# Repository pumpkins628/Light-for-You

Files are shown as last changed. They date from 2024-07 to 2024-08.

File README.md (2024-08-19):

# LightVest🚦 Smart Turn Signal Vest
Welcome to the **LightVest** project! This wearable vest is designed to enhance cyclists' and motorcyclists' safety by providing clear, visible turn signals and hazard lights.
👇 ***Click the image below to watch the introduction video!*** 🎥

<p align="center">
  <a href="https://vm.tiktok.com/ZGe3J54N1/">
    Click to watch the video
  </a>
</p>

## ✨ Features

- **Bluetooth Connectivity**: Automatically connects the vest and remote controller.
- **Button Control**: Control the lights using a handlebar-mounted remote with left, right, and hazard buttons.
- **Automatic Detection**: The vest automatically detects handlebar turns and activates the corresponding signal.
- **Emergency Lights**: Activate hazard lights with a single button press for added safety.
- **Easy to Remove and Clean**: The LED strips are designed to be easily detachable for convenient cleaning.
- **Easy Battery Replacement**: The battery compartment is designed for quick and simple replacement.

## 🛠️ Installation

### Hardware Setup

1. #### Components

| Component | Quantity | Description |
|:---:|:---:|:---:|
| **Arduino Nano** | 2 | Microcontroller for control and communication |
| **Bluetooth Modules (HC-05)** | 2 | For wireless communication between the Arduinos |
| **Accelerometer (MPU6050)** | 1 | Detect handlebar angle |
| **LED Strips** | 1 | For displaying turn signals on the vest |
| **Push buttons** | 2 | Control left, right light |
| **Torch switches** | 1 | Control hazard lights |
| **Battery holder** | 2 | Hold and connect AA batteries |
| **AA batteries** | 6 | Power supply for the vest and remote |
| **Jumper wires** | Several  | For connecting components |
| **Resistors** | Various  | To limit current and protect components |
| **Capacitors** | Various  | For filtering and stabilizing voltage |

2. #### Assembly

 **Bluetooth Pairing**:
   - Use a serial debugging tool to pair the two Bluetooth modules. The relevant software can be found in the `Test` folder.
   
 **Wiring the Components**:
   - Connect all components according to the wiring diagrams provided. The diagrams for the two sections are shown below:
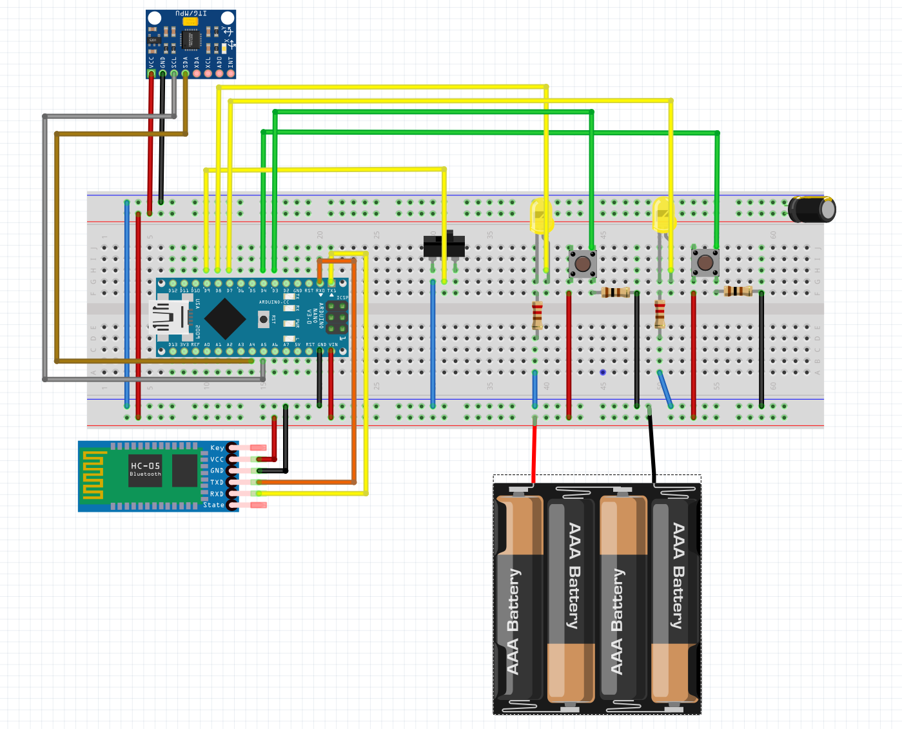
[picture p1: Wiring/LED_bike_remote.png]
Remote Wiring
     - **Remote Controller Wiring Diagram**: 
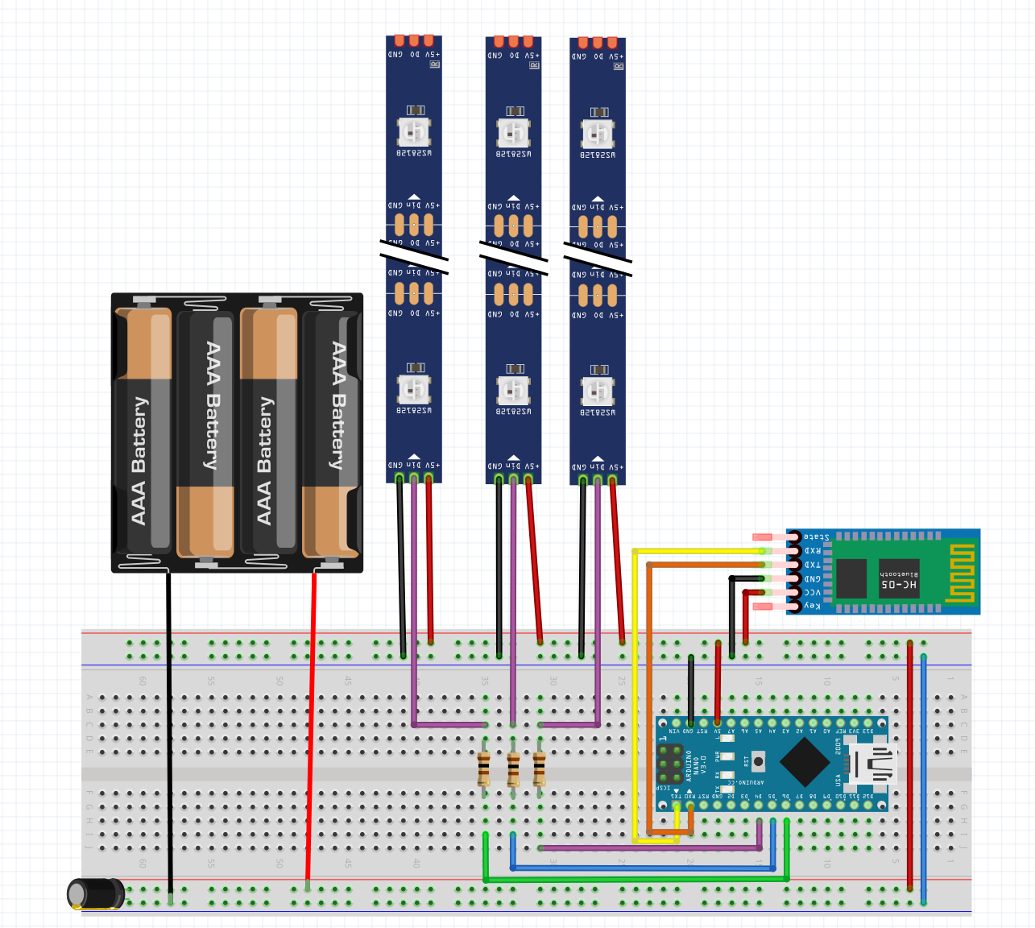
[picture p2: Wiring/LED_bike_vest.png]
Vest Wiring
     - **Vest Wiring Diagram**: 
     
 **PCB Design**:
- The PCB design files are located in the `PCB` folder. If you wish to have your own vest, feel free to download them.

3. #### Enclosure
   - The 3D printing files for the enclosure are located in the `3D_Print` folder. Below is a preview of the enclosure design:
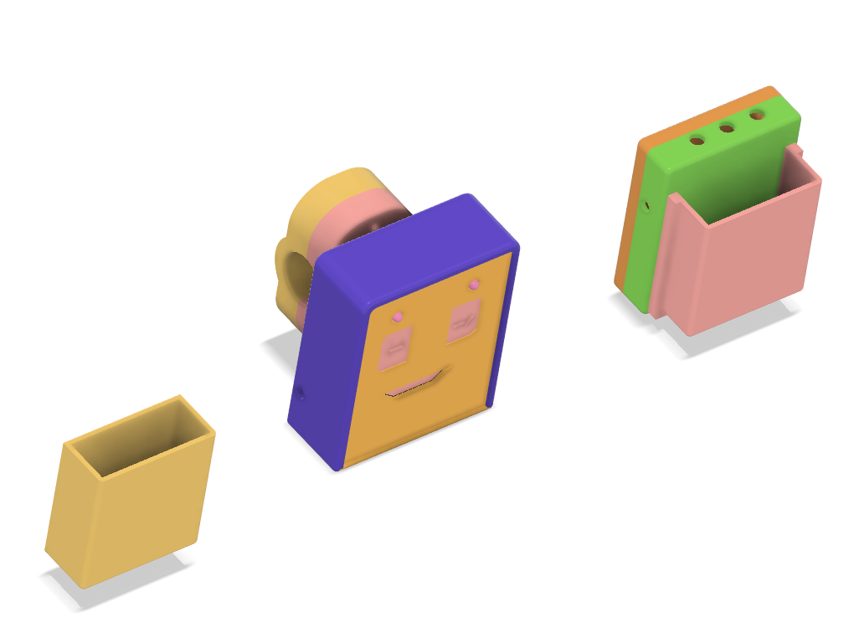
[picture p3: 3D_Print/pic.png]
Enclosure Design
     - **Enclosure Design Preview**: 

## 💻 Software Setup

1. ### Clone the Repository

```bash
git clone https://github.com/pumpkins628/Light-for-You.git
cd Light-for-You
```

2. ### Upload Code

 - Open the Arduino IDE.
- Find the `Code/LED_suit_vest_bluetooth` folder and open the `LED_suit_vest_bluetooth.ino` file.
  Upload this code to the Arduino Nano, which you want to use to control the vest.
- Find the `Code/control` folder and open the `control.ino` file.
  Upload this code to the Arduino Nano, which you want to use to connect the light on the vest.

🚨 **Library Setup**
<br>
- Don't forget to import the required libraries into the Arduino IDE:
The necessary libraries can be found in the `Test` folder.
- To import a library, go to Sketch > Include Library > Add .ZIP Library... in the Arduino IDE, then select the relevant library files from the `Test` folder.

## 🚴‍♂️ Usage

### Power On
- Turn on the vest and remote by clicking their own switches.

### Control Signals
- **Left Turn**: Press the left button on the remote or turn the handlebars left.
- **Right Turn**: Press the right button on the remote or turn the handlebars right.
- **Hazard Lights**: Press the middle button on the remote to activate the hazard lights.

### Ride Safely
- Your vest will automatically display the correct signals based on your inputs!
  <br>
<p align="center">
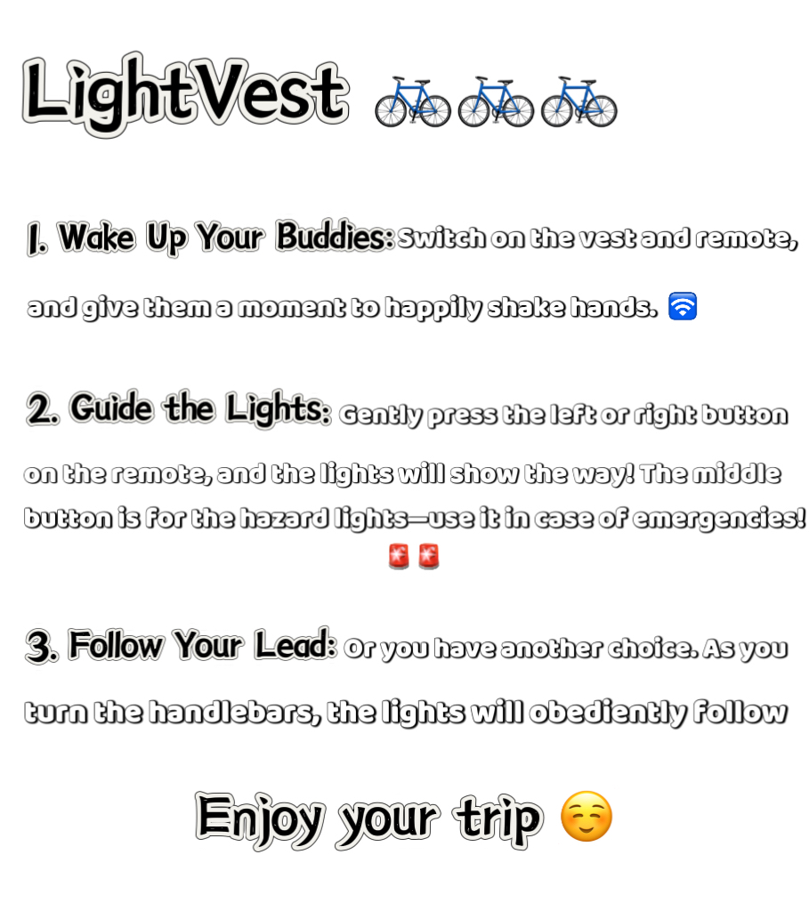
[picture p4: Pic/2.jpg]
Usage
  
</p>

## 🤝 Contributing
I welcome contributions! If you'd like to improve this project, feel free to fork the repository, create a new branch, and submit a pull request!

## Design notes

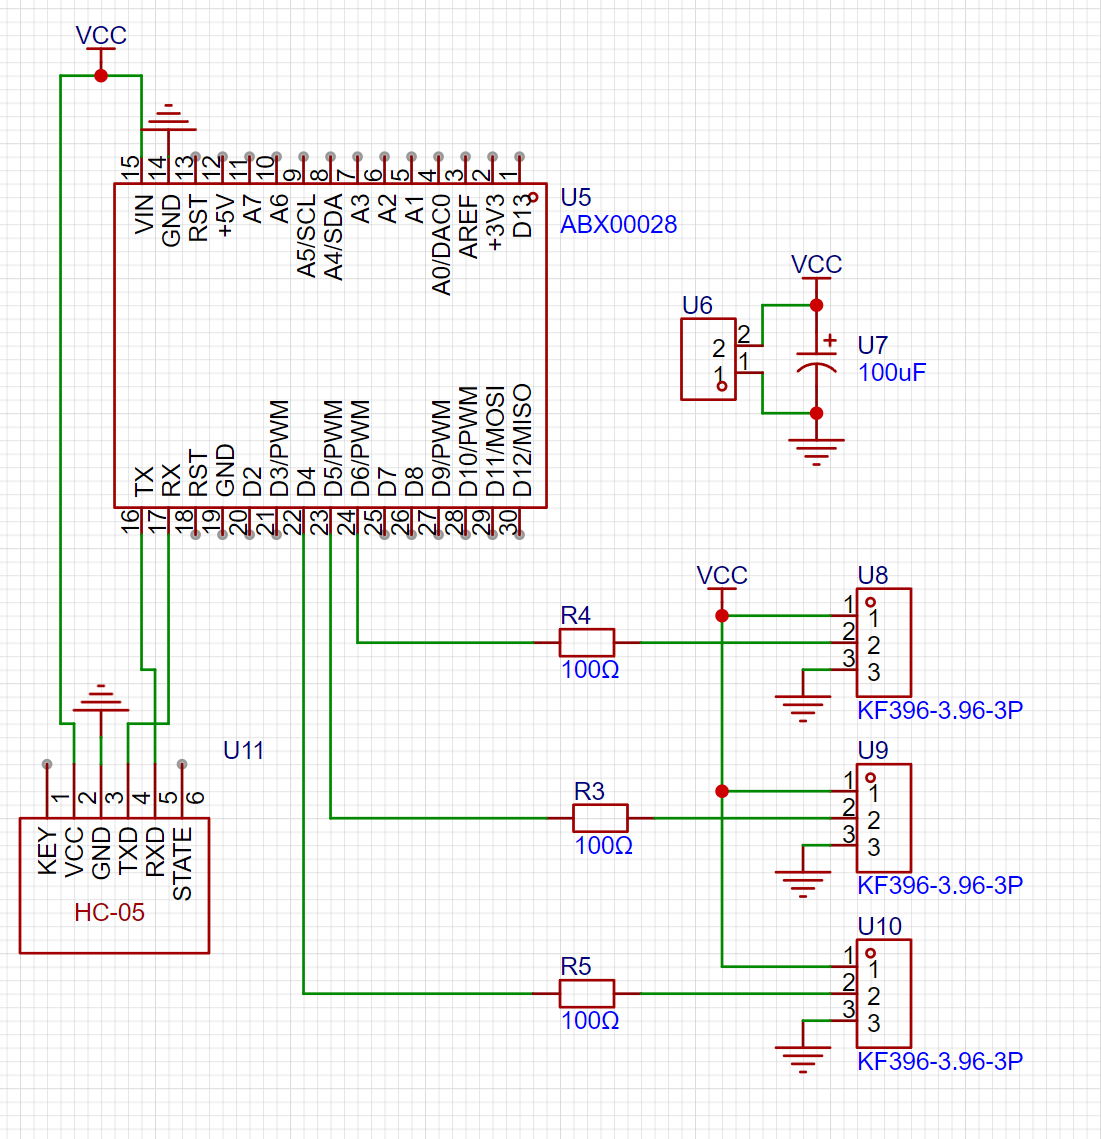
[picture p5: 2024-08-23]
PCB/circuit diagram for vest.png

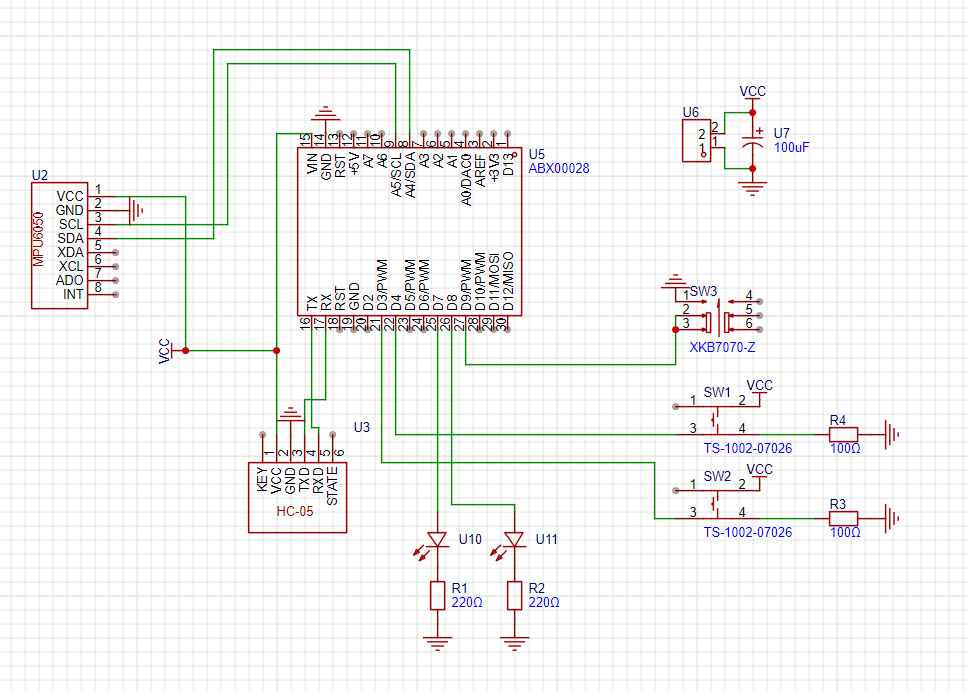
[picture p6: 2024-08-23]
PCB/circuit diagram for remote.png

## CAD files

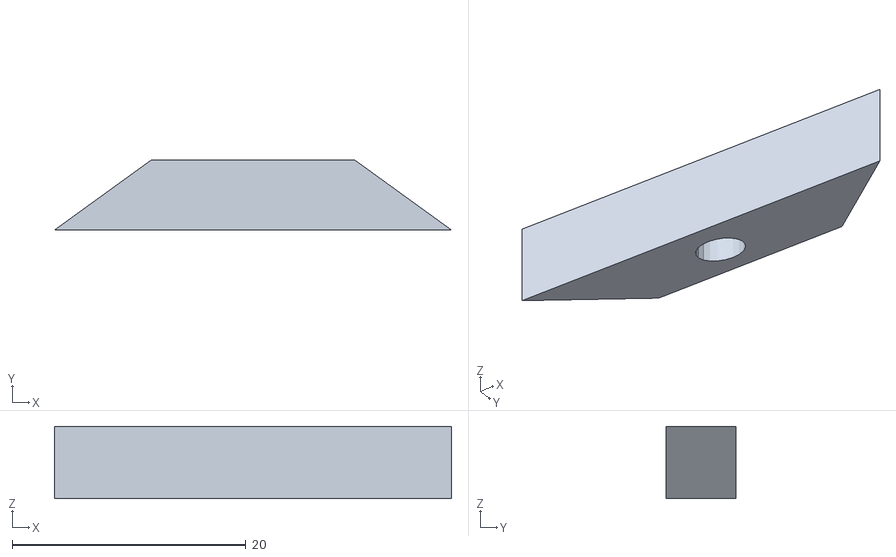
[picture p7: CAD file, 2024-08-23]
3D_Print/Button2.stl
34.0 x 6.00 x 6.18

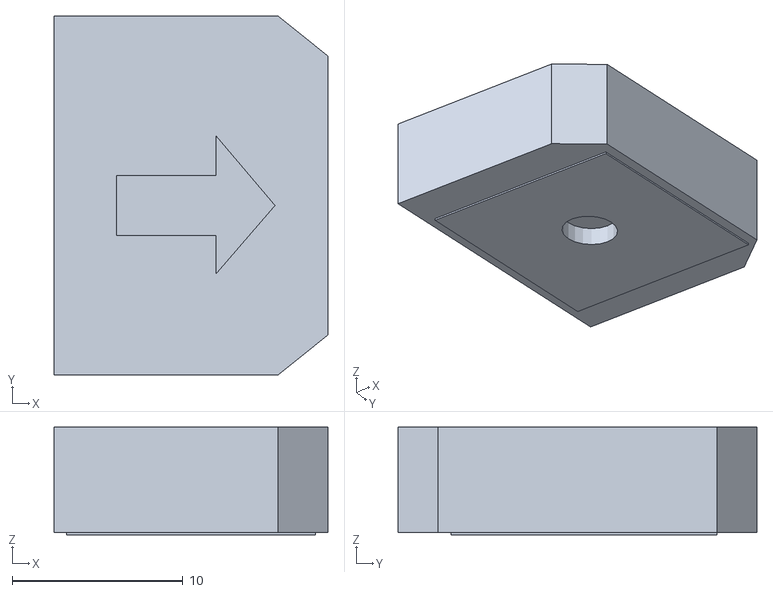
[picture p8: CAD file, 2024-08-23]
3D_Print/Button1.stl
16.0 x 21.0 x 6.30

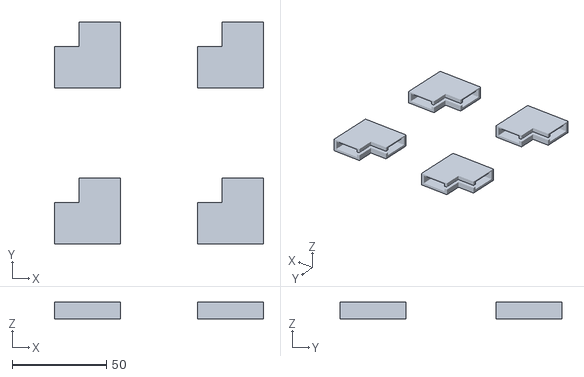
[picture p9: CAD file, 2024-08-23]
3D_Print/clippers.stl
111.0 x 118.0 x 9.00

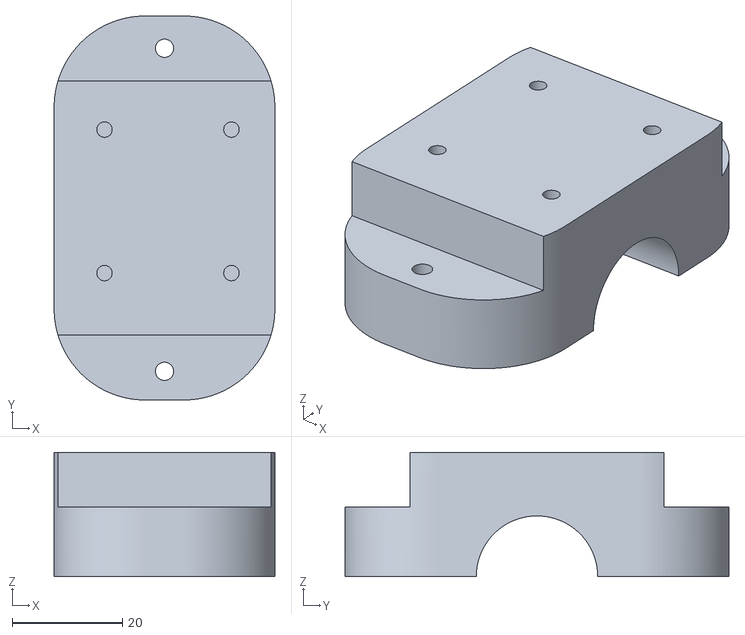
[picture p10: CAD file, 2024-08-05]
3D_Print/Handlebar_Mount1.stl
40.0 x 69.6 x 22.5

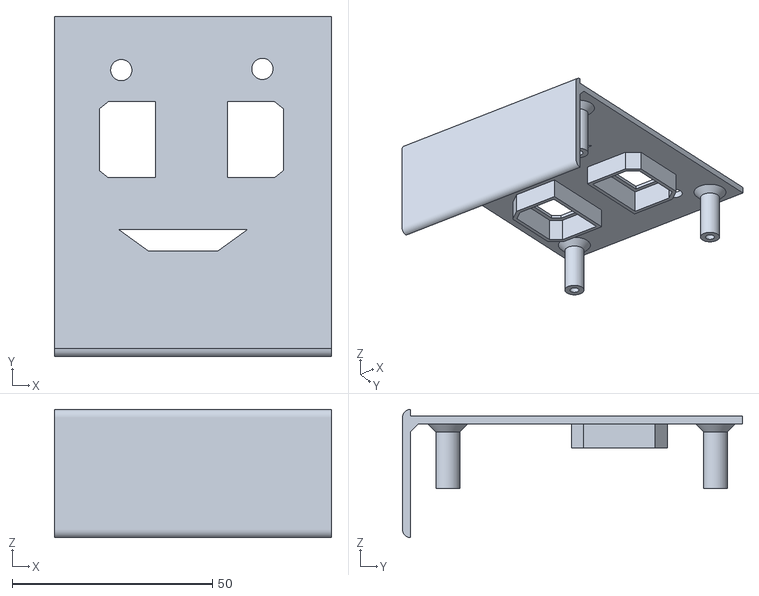
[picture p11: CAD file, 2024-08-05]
3D_Print/Top_Cover.stl
69.1 x 84.9 x 32.0

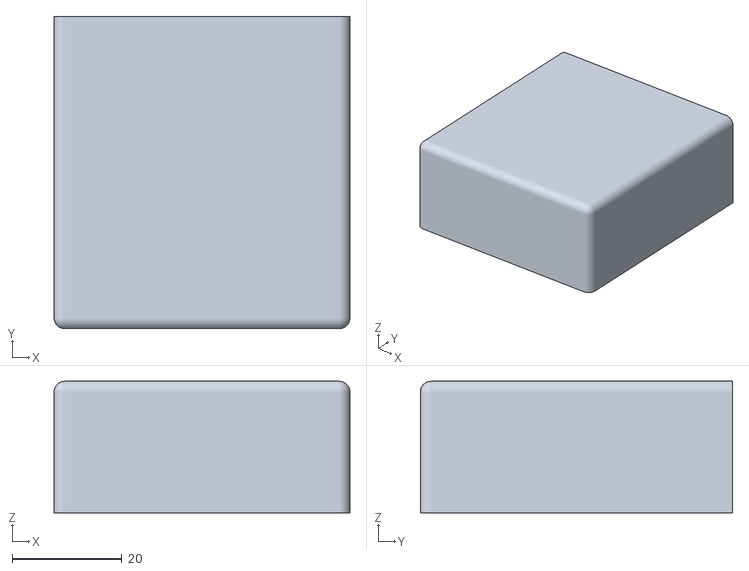
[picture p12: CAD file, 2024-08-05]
3D_Print/Battery_Holder2.stl
54.0 x 57.0 x 24.0

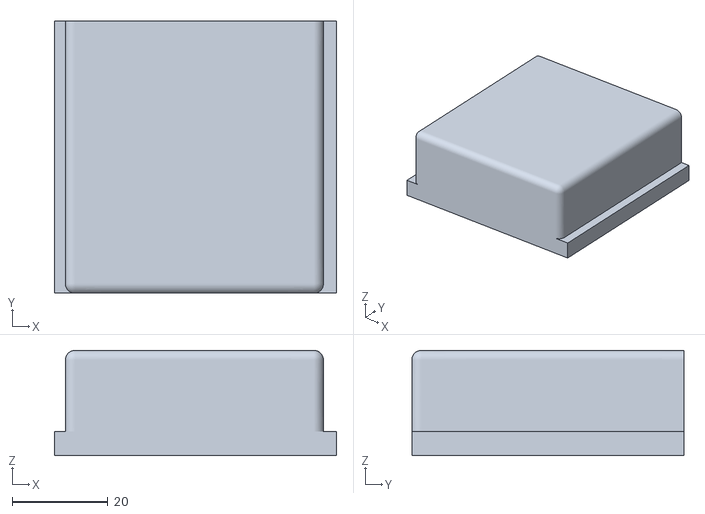
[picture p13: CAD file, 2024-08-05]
3D_Print/Battery_Holder1.stl
59.0 x 57.0 x 22.0

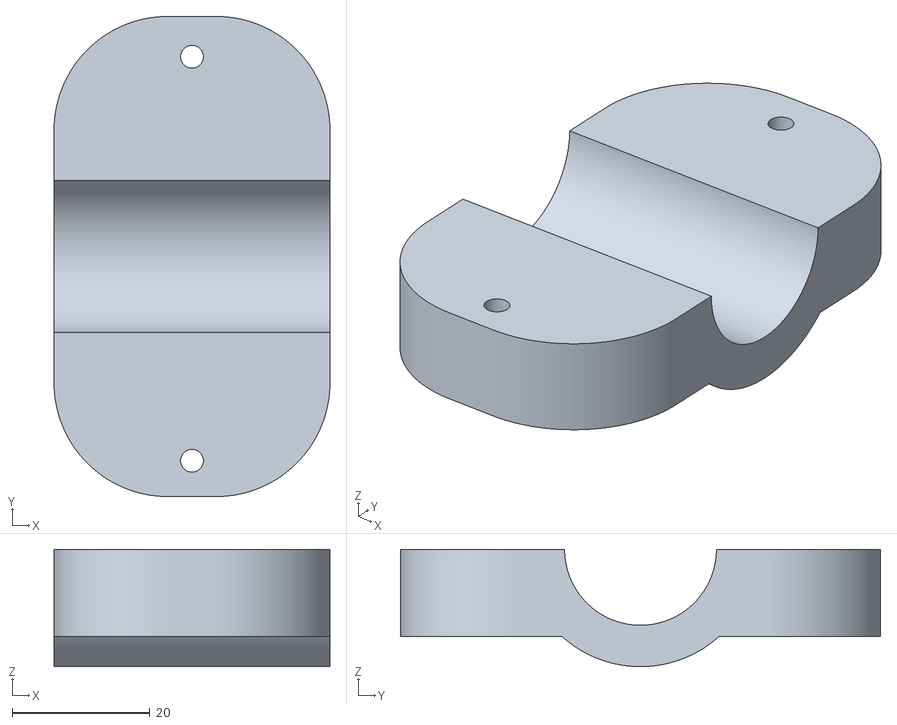
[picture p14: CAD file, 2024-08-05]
3D_Print/Handlebar_Mount2.stl
40.0 x 69.6 x 17.0

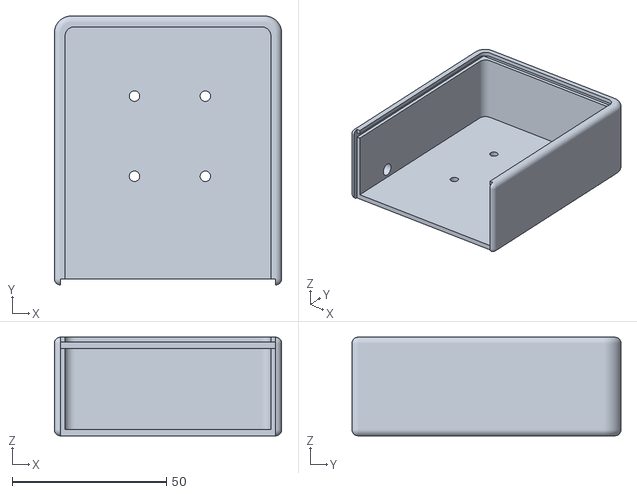
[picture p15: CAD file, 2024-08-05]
3D_Print/Bottom_Cover.stl
73.7 x 87.3 x 32.0

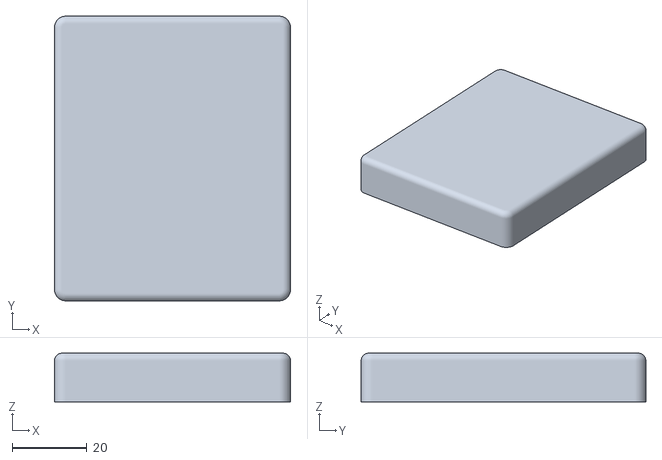
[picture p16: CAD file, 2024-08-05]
3D_Print/Light_Box_Top.stl
63.0 x 76.0 x 13.0

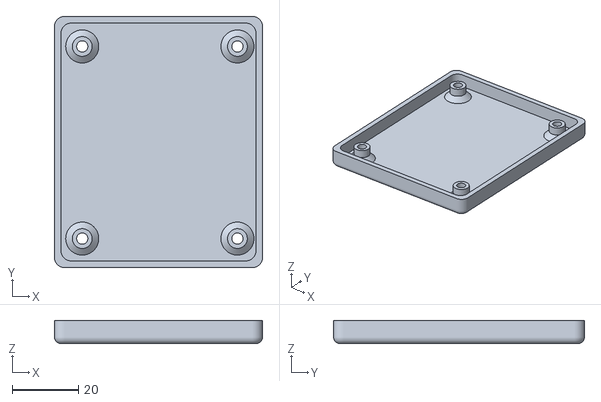
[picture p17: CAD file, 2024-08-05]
3D_Print/Light_Box_Bottom.stl
63.0 x 76.0 x 7.00

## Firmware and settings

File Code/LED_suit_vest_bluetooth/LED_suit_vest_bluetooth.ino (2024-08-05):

#include <Adafruit_NeoPixel.h>
#ifdef __AVR__
#include <avr/power.h> 
#endif

#define LED_BACK    6
#define LED_LEFT    4
#define LED_RIGHT   5

#define LED_COUNT_BACK 32   // Number of leds on the back light strip
#define LED_COUNT_LEFT 12   // Number of leds in the left light strip
#define LED_COUNT_RIGHT 12  // Number of leds in the right light strip
char state = 0; 
int light_delay = 50; 

// Declare our NeoPixel strip_back object
Adafruit_NeoPixel strip_back( LED_COUNT_BACK, LED_BACK, NEO_GRB + NEO_KHZ800);
Adafruit_NeoPixel strip_left(LED_COUNT_LEFT, LED_LEFT, NEO_GRB + NEO_KHZ800);
Adafruit_NeoPixel strip_right(LED_COUNT_RIGHT, LED_RIGHT, NEO_GRB + NEO_KHZ800);



void setup() {
#if defined(__AVR_ATtiny85__) && (F_CPU == 16000000)
  clock_prescale_set(clock_div_1);
#endif

  strip_back.begin();           
  strip_back.show();            
  strip_back.setBrightness(150); 

  strip_left.begin();           
  strip_left.show();            
  strip_left.setBrightness(150); 

  strip_right.begin();           
  strip_right.show();            
  strip_right.setBrightness(150);

  Serial.begin(9600);
  delay(1000);
  powerOnWipe(strip_back.Color(255, 100, 0), 50);
}



void loop() {

  


  if (Serial.available() > 0) { // Checks whether data is comming from the serial port


    state = Serial.read(); // Reads the data from the serial port
    Serial.print(state); // Prints out the value sent

    //Indicate Left
    if (state == 'L') {
      leftBlink();
      delay(light_delay);

    }

    //Indicate Right
    if (state == 'R') {
      rightBlink();
      delay(light_delay);

    }

  if (state == 'H') {
    hazardBlink();
    delay(light_delay);
  }

  }


}

void colorWipeLeft(uint32_t color, int wait) {
  for (int i = 0; i < strip_left.numPixels(); i++) { // For each pixel in strip_back...
    strip_left.setPixelColor(i, color);         //  Set pixel's color (in RAM)
    strip_left.show();                          //  Update strip_back to match
    delay(wait);                           //  Pause for a moment
    strip_left.clear();
  }
}

void powerOnWipe(uint32_t color, int wait) {  // First, sequentially light up all LEDs
  for (int i = 0; i < strip_back.numPixels(); i++) {
    strip_back.setPixelColor(i, color);       // Set color for back strip
    if (i < strip_left.numPixels()) {        // Set color for left and right strips, handling indexing within their bounds
      strip_left.setPixelColor(i, color);
    }
    if (i < strip_right.numPixels()) {
      strip_right.setPixelColor(i, color);
    }

    
    strip_back.show();                 // Update strips with new color
    strip_left.show();
    strip_right.show();
    delay(wait);    // Pause to create the effect of lighting up one LED at a time
  }

  // Keep all LEDs on for a moment before blinking
  delay(500); // Adjust this delay as needed


  for (int j = 0; j < 2; j++) {   // Blink twice
   
    strip_back.clear();  // Turn off all LEDs
    strip_left.clear();
    strip_right.clear();
    strip_back.show();
    strip_left.show();
    strip_right.show();
    delay(200); // Off period

    // Turn on all LEDs
    for (int i = 0; i < strip_back.numPixels(); i++) {
      strip_back.setPixelColor(i, color);
      if (i < strip_left.numPixels()) {
        strip_left.setPixelColor(i, color);
      }
      if (i < strip_right.numPixels()) {
        strip_right.setPixelColor(i, color);
      }
    }
    strip_back.show();
    strip_left.show();
    strip_right.show();
    delay(200); // On period
  }

  // Finally, turn off all LEDs
  strip_back.clear();
  strip_left.clear();
  strip_right.clear();
  strip_back.show();
  strip_left.show();
  strip_right.show();
}


void rightBlink() {

  for (int i = 0; i < 4; i++) { // For each pixel in strip_back...

    colorBlinkersRight(strip_left.Color(255,   100,   0), 50); //Yellow
    turnRight(strip_back.Color(255, 100, 0), 50);
    delay(400);
    colorBlinkersRight(strip_left.Color(0,   0,   0), 25); //Yellow
    turnRight(strip_back.Color(0, 0, 0), 50);
    delay(300);

  }
}

void colorBlinkersRight(uint32_t c, int wait) {

  strip_right.setPixelColor(0, c);
  strip_right.setPixelColor(1, c);
  strip_right.setPixelColor(2, c);
  strip_right.setPixelColor(3, c);
  strip_right.setPixelColor(4, c);
  strip_right.setPixelColor(5, c);
  strip_right.setPixelColor(6, c);
  strip_right.setPixelColor(7, c);
  strip_right.setPixelColor(8, c);
  strip_right.setPixelColor(9, c);
  strip_right.setPixelColor(10, c);
  strip_right.setPixelColor(11, c);
  
  strip_right.show();
  delay(wait);
  strip_right.clear();
  delay(wait);

}



void hazardBlink() {

  for (int i = 0; i < 4; i++) { // For each pixel in strip_back...

    colorBlinkersLeft(strip_left.Color(255,   100,   0), 50); //Yellow
    colorBlinkersRight(strip_right.Color(255,   100,   0), 50); //Yellow
    colorBlinkersHazard(strip_back.Color(255, 100, 0), 50); //for back

    delay(400);
    colorBlinkersLeft(strip_left.Color(0,   0,   0), 25); //Yellow
    colorBlinkersRight(strip_right.Color(0,   0,   0), 50); //Yellow
    colorBlinkersHazard(strip_back.Color(0, 0, 0), 50); //for back


    delay(300);

  }
}


void leftBlink() {

  for (int i = 0; i < 4; i++) { // For each pixel in strip_back...

    colorBlinkersLeft(strip_left.Color(255,   100,   0), 50); //Yellow
    turnLeft(strip_back.Color(255, 100, 0), 50); //for back
    delay(400);
    colorBlinkersLeft(strip_left.Color(0,   0,   0), 25); //Yellow
    turnLeft(strip_back.Color(0, 0, 0), 50); //for back

    delay(300);

  }
}

void colorBlinkersLeft(uint32_t c, int wait) {



  strip_left.setPixelColor(0, c);
  strip_left.setPixelColor(1, c);
  strip_left.setPixelColor(2, c);
  strip_left.setPixelColor(3, c);
  strip_left.setPixelColor(4, c);
  strip_left.setPixelColor(5, c);
  strip_left.setPixelColor(6, c);
  strip_left.setPixelColor(7, c);
  strip_left.setPixelColor(8, c);
  strip_left.setPixelColor(9, c);
  strip_left.setPixelColor(10, c);
  strip_left.setPixelColor(11, c);
 
  strip_left.show();
  delay(wait);
  strip_left.clear();
  delay(wait);

}


void colorBlinkersHazard(uint32_t c, int wait) {

  int i=0;
  for(i=0;i<32;i++)
  {
    strip_back.setPixelColor(i, c);
  }
  
  strip_back.show();
  delay(wait);
  strip_back.clear();
  delay(wait);

}


void colorWipeRight(uint32_t color, int wait) {
  for (int i = 0; i < strip_right.numPixels(); i++) { // For each pixel in strip_back...
    strip_right.setPixelColor(i, color);         //  Set pixel's color (in RAM)
    strip_right.show();                          //  Update strip_back to match
    delay(wait);                           //  Pause for a moment
    strip_right.clear();
  }
}




// Fill the dots one after the other with a color
void turnRight(uint32_t c, uint8_t wait) {

  strip_back.setPixelColor(0, c);
  strip_back.setPixelColor(1, c);
  strip_back.setPixelColor(2, c);
  strip_back.setPixelColor(3, c);
  strip_back.setPixelColor(4, c);
  strip_back.setPixelColor(5, c);
  strip_back.setPixelColor(6, c);
  strip_back.setPixelColor(7, c);

  strip_back.setPixelColor(8, c);
  strip_back.setPixelColor(9, c);
  strip_back.setPixelColor(10, c);
  strip_back.setPixelColor(11, c);
  strip_back.setPixelColor(12, c);
  strip_back.setPixelColor(13, c);
  strip_back.setPixelColor(14, c);
  strip_back.setPixelColor(15, c);



  strip_back.show();
  delay(wait);
  strip_back.clear();


}


// Fill the dots one after the other with a color
void turnLeft(uint32_t c, uint8_t wait) {

 

  strip_back.setPixelColor(16, c);
  strip_back.setPixelColor(17, c);
  strip_back.setPixelColor(18, c);
  strip_back.setPixelColor(19, c);
  strip_back.setPixelColor(20, c);
  strip_back.setPixelColor(21, c);
  strip_back.setPixelColor(22, c);
  strip_back.setPixelColor(23, c);


  strip_back.setPixelColor(24, c);
  strip_back.setPixelColor(25, c);
  strip_back.setPixelColor(26, c);
  strip_back.setPixelColor(27, c);
  strip_back.setPixelColor(28, c);
  strip_back.setPixelColor(29, c);
  strip_back.setPixelColor(30, c);
  strip_back.setPixelColor(31, c);



  strip_back.show();
  delay(wait);
  strip_back.clear();


}


void colorShow(uint32_t color, int wait) {
  for (int i = 0; i < strip_back.numPixels(); i++) { // For each pixel in strip_back...
    strip_back.setPixelColor(i, color);         //  Set pixel's color (in RAM)
  }
  strip_back.show();                          //  Update strip_back to match
  //delay(wait);                           //  Pause for a moment
  strip_back.clear();

}



void clearLights() {
  strip_left.clear();
  strip_right.clear();
  strip_back.clear();
}

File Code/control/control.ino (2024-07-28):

#include<Wire.h>


const int buttonPin_Left = 3;    
const int buttonPin_Right = 4;    
const int buttonPin_Hazard = 9;

const int ledPin_Left =  8;      // the number of the LED pin
const int ledPin_Right =  7;      // the number of the LED pin



int buttonState_Left = 0;         // variable for reading the pushbutton status
int buttonState_Right = 0;         // variable for reading the pushbutton status
int buttonState_Hazard=0;

const int MPU_addr = 0x68;
int16_t AcX, AcY, AcZ, Tmp, GyX, GyY, GyZ;

int minVal = 265;
int maxVal = 402;

double x;
double y;
double z;

bool bool_caliberate = false;
int response_time = 400;


bool offset_pos = false;



void setup() {
  // initialize the LED pin as an output:
  pinMode(ledPin_Left, OUTPUT);
  pinMode(ledPin_Right, OUTPUT);

  // initialize the pushbutton pin as an input:
  pinMode(buttonPin_Left, INPUT);
  pinMode(buttonPin_Right, INPUT);
  pinMode(buttonPin_Hazard, INPUT_PULLUP);


  Wire.begin();
  Wire.beginTransmission(MPU_addr);
  Wire.write(0x6B);// PWR_MGMT_1 register
  Wire.write(0); // set to zero (wakes up the MPU-6050)
  Wire.endTransmission(true); Wire.begin();
  Serial.begin(9600);
  delay(1000);

}

void loop() {

  
  MPU_debug();


  // read the state of the pushbutton value
  buttonState_Left = digitalRead(buttonPin_Left);
  buttonState_Right = digitalRead(buttonPin_Right);
  buttonState_Hazard = digitalRead(buttonPin_Hazard);
  
  if(buttonState_Hazard == LOW)
  {
    Serial.print("H");
    digitalWrite(ledPin_Left, HIGH);
    digitalWrite(ledPin_Right, HIGH);
    delay(5000);
  }
  else
  {
    
  }

  // check if the pushbutton is pressed. If it is, the buttonState is HIGH
  if (buttonState_Left == HIGH) {
    // turn LED on
    Serial.print("L");
    digitalWrite(ledPin_Left, HIGH);
    delay(500);
    buttonState_Right = 0;
  } else {
    // turn LED off
    digitalWrite(ledPin_Left, LOW);
  }
  
  if (buttonState_Right == HIGH) {
    // turn LED on
    Serial.print("R");
    digitalWrite(ledPin_Right, HIGH);
    delay(500);
    buttonState_Left = 0;

  } else {
    // turn LED off
    digitalWrite(ledPin_Right, LOW);
    buttonState_Left = LOW;
    buttonState_Right = LOW;
  }



 
  GetMpuValue1(MPU_addr);


  if (offset_pos == false) {
   
    if ( GyZ > 15000) {
      Serial.println("L");
      digitalWrite(ledPin_Left, HIGH);
      digitalWrite(ledPin_Right, LOW);
      offset_pos = true;

      delay(response_time);
    }
  }

  if (offset_pos == true) {
    if ( GyZ > 15000) {
      Serial.println("L Offset centre");
      offset_pos = false;
      delay(response_time);
    }
  }


  if (offset_pos == true) {
    if ( GyZ < -15000) {
      Serial.println("R Offset centre");      ;
      delay(response_time);
      offset_pos = false;

    }
  }



  if (offset_pos == false) {
    
    if ( GyZ < -15000) {
      Serial.println("R");
      digitalWrite(ledPin_Right, HIGH);
      digitalWrite(ledPin_Left, LOW);
      delay(response_time);
      offset_pos = true;

    }
  }



}

void button_debug() {
  Serial.print("Left: ");
  Serial.print(buttonState_Left);
  Serial.print("\t");
  Serial.print("Right: ");
  Serial.println(buttonState_Right);

}


void GetMpuValue1(const int MPU) {

  Wire.beginTransmission(MPU);
  Wire.write(0x3B); // starting with register 0x3B (ACCEL_XOUT_H)
  Wire.endTransmission(false);
  Wire.requestFrom(MPU, 14, true); // request a total of 14 registers

  AcX = Wire.read() << 8 | Wire.read(); // 0x3B (ACCEL_XOUT_H) & 0x3C (ACCEL_XOUT_L)
  AcY = Wire.read() << 8 |  Wire.read(); // 0x3D (ACCEL_YOUT_H) & 0x3E (ACCEL_YOUT_L)
  AcZ = Wire.read() << 8 | Wire.read(); // 0x3F (ACCEL_ZOUT_H) & 0x40 (ACCEL_ZOUT_L)

  Tmp = Wire.read() << 8 | Wire.read(); // 0x41 (TEMP_OUT_H) & 0x42 (TEMP_OUT_L)

  int xAng = map(AcX, minVal, maxVal, -90, 90);
  int yAng = map(AcY, minVal, maxVal, -90, 90);
  int zAng = map(AcZ, minVal, maxVal, -90, 90);

  GyX = Wire.read() << 8 | Wire.read(); // 0x43 (GYRO_XOUT_H) & 0x44 (GYRO_XOUT_L)
  GyY = Wire.read() << 8 | Wire.read(); // 0x45 (GYRO_YOUT_H) & 0x46 (GYRO_YOUT_L)
  GyZ = Wire.read() << 8 | Wire.read(); // 0x47 (GYRO_ZOUT_H) & 0x48 (GYRO_ZOUT_L)

  x = RAD_TO_DEG * (atan2(-yAng, -zAng) + PI) + 4; //offset by 4 degrees to get back to zero
  y = RAD_TO_DEG * (atan2(-xAng, -zAng) + PI);
  z = RAD_TO_DEG * (atan2(-yAng, -xAng) + PI);

}

void MPU_debug() {
#if 0
    Serial.print("AngleX= ");
    Serial.print(x);
    Serial.print("\t");
  
    Serial.print("AngleY= ");
    Serial.print(y);
    Serial.print("\t");
  
    Serial.print("AngleZ= ");
    Serial.println(z);
    Serial.print("\t");
    Serial.println("-----------------------------------------");
  
    Serial.print(" | GyX = ");
    Serial.print(GyX);
    Serial.print(" | GyY = ");
    Serial.print(GyY);
    Serial.print(" | GyZ = ");
    Serial.println(GyZ);
#endif
}

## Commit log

2024-08-05 Update LED_suit_vest_bluetooth.ino
    Add a startup animation and remove the test rainbow effect
2024-08-05 Add library for Arduino IDE
    If a missing library issue occurs during compilation, you can import the entire compressed package.
2024-08-23 Update the changed PCB folder
2024-08-23 Add button model
    [Button1.stl, Button2.stl, clippers.stl]
